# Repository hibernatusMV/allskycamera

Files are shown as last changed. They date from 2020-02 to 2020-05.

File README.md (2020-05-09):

# Allsky Camera

## Hardware
- Raspberry Pi 3B+ / 4
- LED Red
- LED Green
- Temperature sensor DS 18B20
- Relais EIN Kanal Relaismodul Bord Schild Für PIC AVR DSP ARM https://amzn.to/2vrqiVI

## Wiring
**_Power LED_**

| RasPi Pin | Pin | LED |
| --- |---|:---:|
| 1 | 3.3V | (+) |
| 6 | GND | (-) |

**_Activity LED_**
| RasPi Pin | Pin | LED |
| --- |---|:---:|
| 38 | GPIO20 | (+) |
| 39 | GND | (-) |

**_Heater Switch Relay_**
| RasPi Pin | Relay | |
| --- |---|---|
| 2 | (+) | |
| 4 | IN | Relay input |
| 9 | COM | Resistors (GND) |
| 11 | S | Signal |
| 14 | (-) | GND |

**_Temperature Sensor_**
| RasPi Pin | DS18B20 |
| --- |---|
| 7 | Data |
| 17 | 3.3V |
| 21 | GND |

**_Raspberry Pi 3 B+ Pinout_**
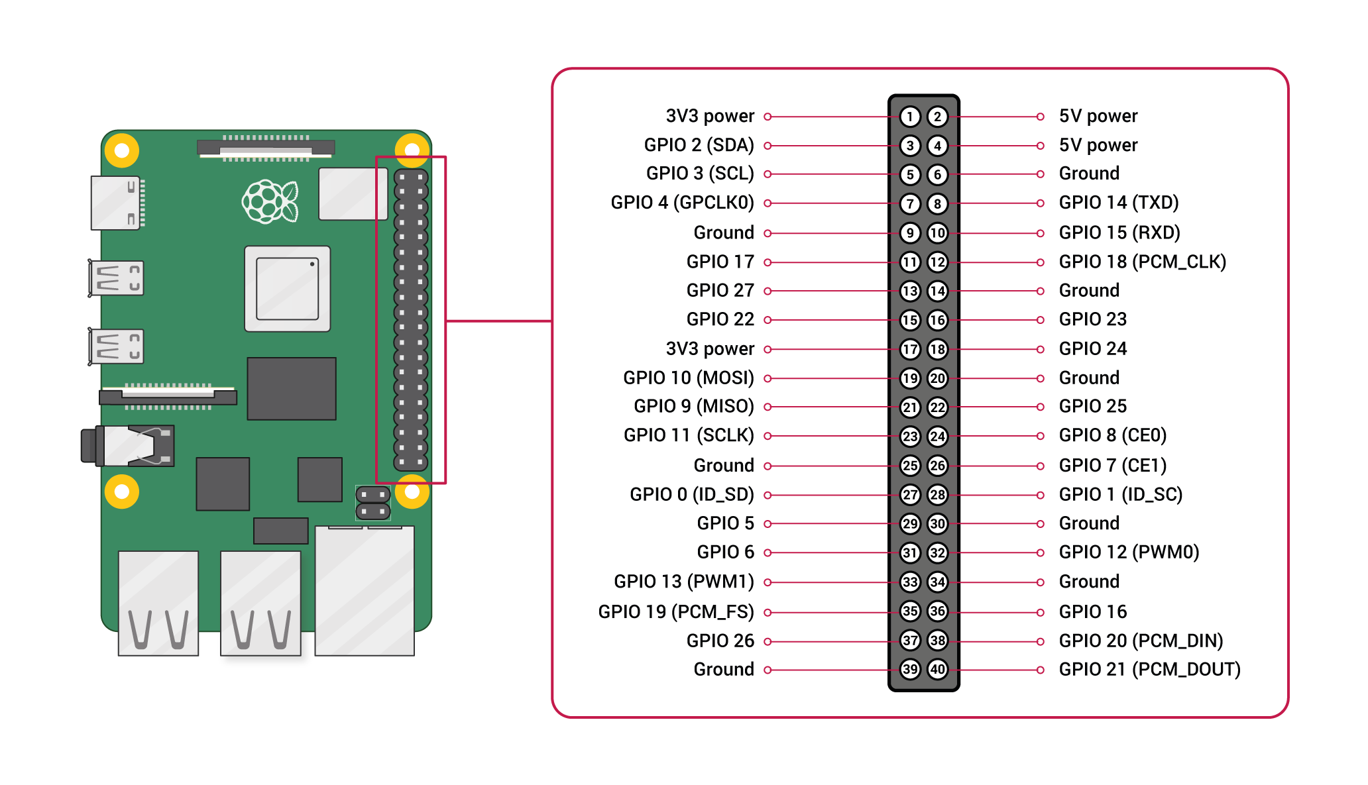
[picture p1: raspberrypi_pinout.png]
RaspPi3B_Pinout Raspberry Pi 3 B+ Pinout


## Raspberry Pi Environment
**_Shell scripts and cronjobs_**
1. Create two new folder named bin and log in /home/pi/

   ```bash
   mkdir bin
   mkdir log
   ```
   
2. Copy shell scripts to the bin directory
3. To make the scripts work, WiringPi has to be installed (normally it is pre-installed). Important for Pi 4 users:
   WiringPi has to be 2.52 or later. Check with
   
   ```bash
   gpio -v
   ```   
   
   To upgrade to the latest version do the following:
   
   ```bash
   cd /tmp
   wget https://project-downloads.drogon.net/wiringpi-latest.deb
   sudo dpkg -i wiringpi-latest.deb
   ```
   
   After successful installation run again
   
   ```bash
   gpio -v
   ```
   
   to check for the installed version.
4. Additionally bc has to be installed (if not already installed).
   Install with ``` sudo apt-get install bc ```
5. Edit crontab ``` crontab -e ```
6. Add the cronjob ``` */1 * * * * /home/pi/bin/tempGuard.sh >>/home/pi/log/$(date +\%Y\%m\%d)_tempGuard.log 2>&1 ```

**_Installing Telegramm and Telegramm Bot_**

1. Follow the link to setup a Telegramm bot :
[Using Telegram Bot with Raspberry Pi](https://circuitdigest.com/microcontroller-projects/raspberry-pi-telegram-bot) until Step 4.

2. Install telebot to communicate with Telegramm.

```bash
sudo apt-get install python-pip
sudo pip install telepot
```

3. Install emoji library ``` pip install emoji --upgrade ```
4. Create a new folder named python in /home/pi/:

```bash
mkdir python
```

5. Copy the python scripts and subfolder into the python directory.
6. Copy the service script allskybot.service into /lib/systemd/system/ (copy as root).
7. Enable newly added service to start at Pi startup

```bash
sudo systemctl daemon-reload
sudo systemctl enable allskybot.service
sudo systemctl start allskybot.service
```

8. Check status of the service
```bash
sudo systemctl status allskybot.service
```

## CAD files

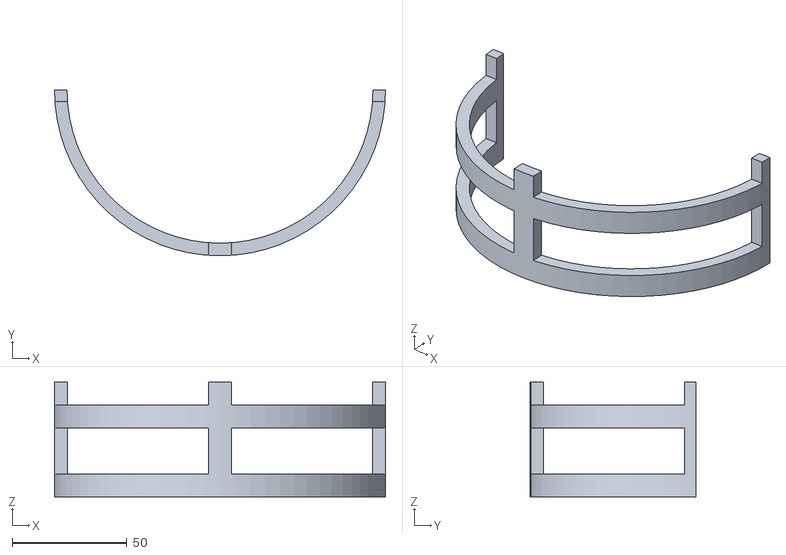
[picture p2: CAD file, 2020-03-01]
stl/AllSkyCamera_Standfuss.stl
144.5 x 72.2 x 50.0

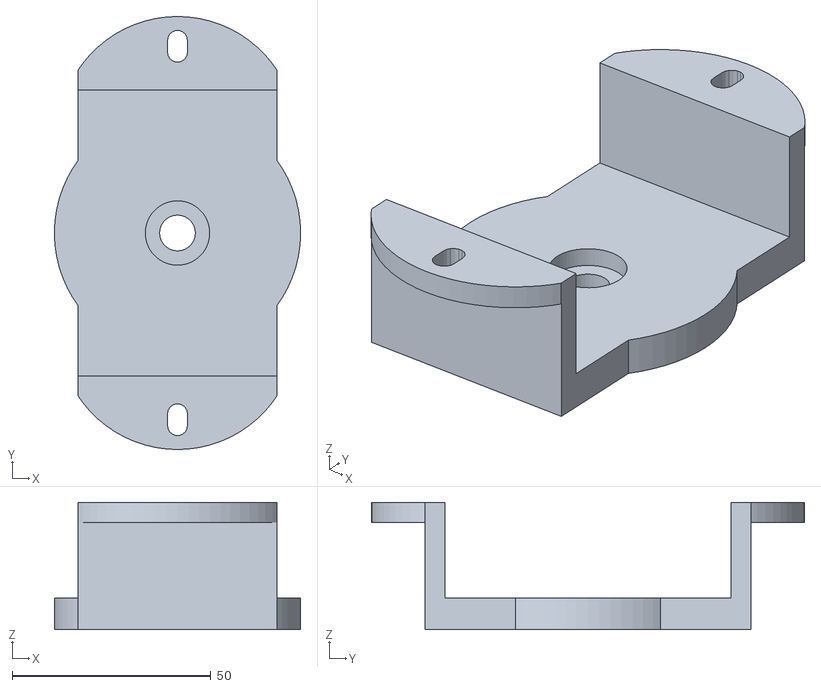
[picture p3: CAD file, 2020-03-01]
stl/AllSkyCamera_ASI_Halterung.stl
62.0 x 109.0 x 32.0

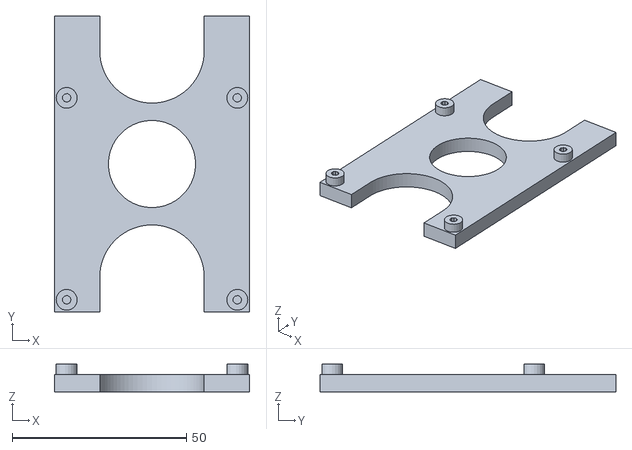
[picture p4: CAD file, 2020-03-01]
stl/AllSkyCamera_PiHalterung.stl
56.0 x 85.0 x 8.00

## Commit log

2020-03-01 changed to shell scripts and adding stl files for 3D printing
    [AllSkyCamera_ASI_Halterung.stl, AllSkyCamera_PiHalterung.stl, AllSkyCamera_Standfuss.stl]
2020-03-03 update allskybot with menu buttons
2020-03-03 updating allskyBot.py with new button menu
2020-05-10 reworked function for getting CPU temperature
2026-01-19 Update README.md
    Added 1-Wire enabling
